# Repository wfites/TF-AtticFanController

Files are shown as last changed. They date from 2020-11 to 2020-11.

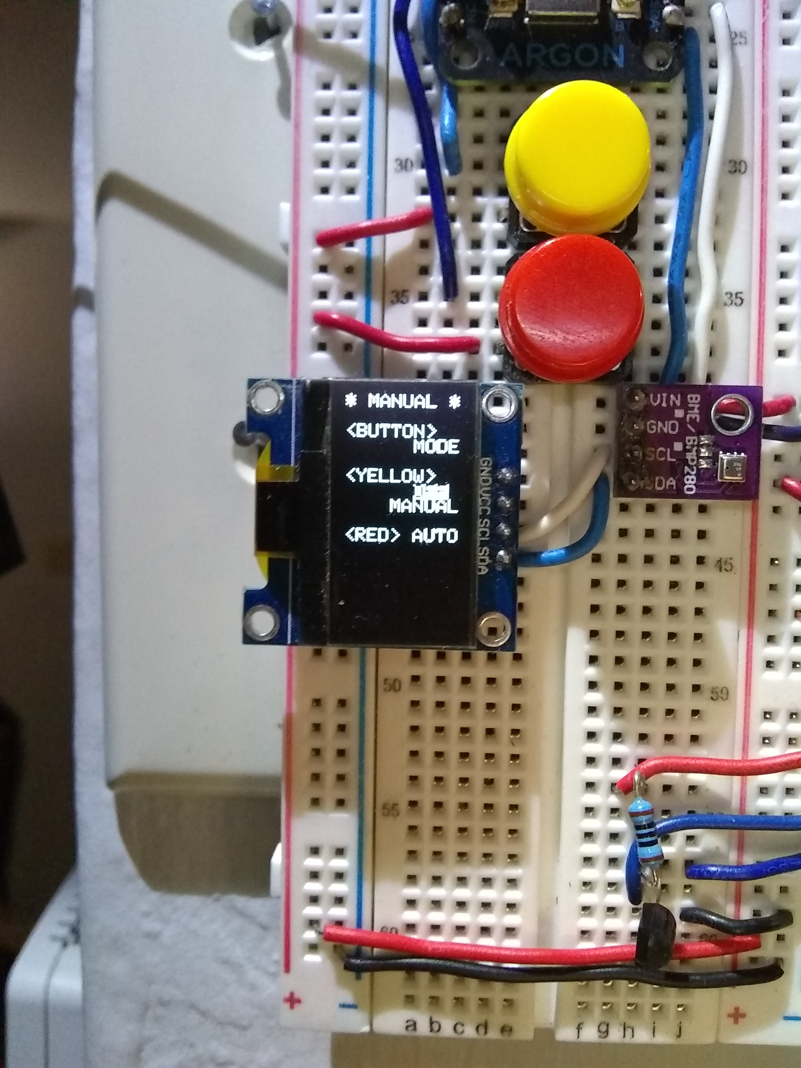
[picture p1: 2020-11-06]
Photos/ControllerManualModeScreen.jpg

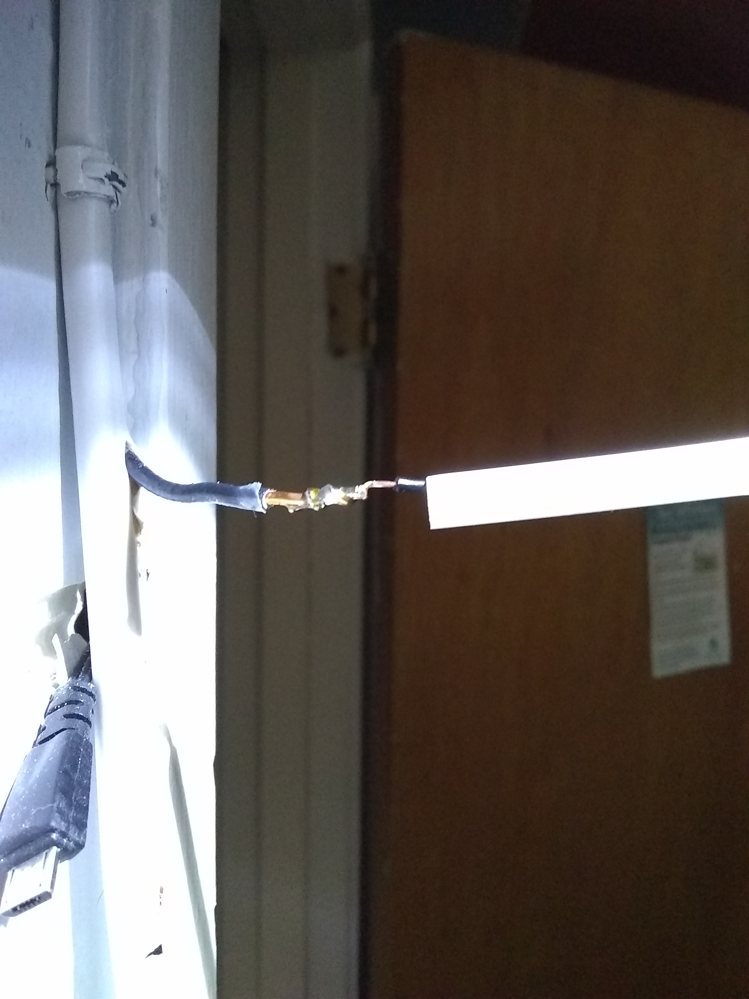
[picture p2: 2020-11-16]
Photos/Soldered14-18GaJointwHeatShrink.jpg

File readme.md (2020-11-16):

Attic Fan Controller: Project Progress
--------------------------------------
11/9/20:	Attic Fan Power Cord Channel Install
	Finish installing channel pcs 2 & 3 adj to door moulding, solder 14 ga extension wire pc#2/2 to spliced power cord hot wire, clean up debris around furnace closet. Install complete.

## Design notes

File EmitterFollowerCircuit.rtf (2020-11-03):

The common collector transistor circuit configuration gains its name from the fact that the collector circuit is common to both input and output circuits, the base being associated with only the input, then the emitter with the output only.

The other name for the common collector is emitter follower. This name is derived from the fact that the emitter voltage "follows" that of the base circuit - the circuit has unit voltage gain.

The emitter follower transistor amplifier has a very straightforward circuit. The base is connected to the previous stage, and often this may be directly connected as this can save on additional bias resistors which lower the input impedance and hence increase the loading to the previous stage.
Common collector transistor configuration showing the base connection common to both input and output circuits
Transistor common collector circuit configuration

Looking at the circuit it can be seen that although the emitter voltage follows that of the base, in DC terms it is actually less than that of the base by a voltage equal to the PN junction drop between the base and emitter. Typically this is 0.6 volts for a silicon transistor and 0.2 to 0.3 for germanium transistors, although these are not widely used these days.

As the emitter voltage follows that of the base, this means that the input and output are exactly in phase and not shifted by 180° as in the case of the common emitter amplifier.
Emitter follower transistor amplifier characteristics summary

The table below gives a summary of the major characteristics of the common collector, emitter follower transistor amplifier.

Common collector, emitter follower transistor amplifier characteristics

Parameter Characteristics
Current gain High
Voltage gain Zero
Power gain Medium
Input / output phase relationship 0°
Input resistance High
Output resistance Low

One key aspect of the characteristic is the input impedance. As it is normally used as a buffer amplifier, this is the key parameter.

The input resistance can easily be calculated for a circuit because it is â times the resistor R1, where â is the forward current gain of the transistor.
Emitter follower input impedance
Emitter follower input resistance
DC coupled emitter follower, common collector circuit

The simplest way of connecting an emitter follower is to directly couple the input as shown below. Often the collector of the previous stage will be at approximately the mid rail voltage, and this means that it can be directly coupled to the buffer stage.
Using a directly coupled emitter follower circuit
Directly coupled emitter follower circuit

Choose transistor: As with other forms of transistor circuit, the transistor should be chosen to meet the anticipated requirements.
Emitter resistor value: The voltage on the emitter is easy to define. It is simply that appearing at the previous stage. Say for example this is half the rail voltage, then the voltage on the emitter Q1 will be 0.5V (for a silicon transistor) less than this - the drop of the base emitter junction. Simply calculate the value of the resistor for the current required.
Emitter follower input resistance: The input resistance of the circuit is effectively â times the emitter resistor, R1.

AC coupled emitter follower, common collector circuit

It is not always possible to directly couple the emitter follower, common collector buffer. When this is the case, it is necessary to add a few additional electronic components: coupling capacitors and bias resistors to the circuit.
Emitter follower circuit with input and output AC coupling and bias resistors
AC coupled emitter follower circuit

The emitter follower can be designed and electronic component values determined using the design flow below as a basis:

Choose transistor: As before, the transistor type should be chosen according to the anticipated performance requirements.
Select emitter resistor: Choosing an emitter voltage of about half the supply voltage to give the most even range before the onset of any clipping, determine the current required from the impedance of the following stage.
Determine base current: The maximum base current is the collector current divided by â (or hfe which is essentially the same).
Determine the base voltage: The base voltage is simply the emitter voltage plus the base emitter junction voltage - this is 0.6 volts for silicon and 0.2 volts for germanium transistors.
Determine base resistor values: Assume a current flowing through the chain R1 + R2 of around ten times that of the base current required. Then select the correct ratio of the resistors to provide the voltage required at the base.
Determine value of input capacitor value: The value of the input capacitor should equal the resistance of the input circuit at the lowest frequency to give a -3dB fall at this frequency. The total impedance of the circuit will be â times R3 plus any resistance external to the circuit, i.e. the source impedance. The external resistance is often ignored as this is likely to not to affect the circuit unduly.
Determine output capacitor value : Again, the output capacitor is generally chosen to equal the circuit resistance at the lowest frequency of operation. The circuit resistance is the emitter follower output resistance plus the resistance of the load, i.e. the circuit following.
Re-evaluate assumptions: In the light of the way the circuit has developed, re-assess any circuit assumptions to ensure they still hold valid. Aspects such as the transistor choice, current consumption values, etc.

The emitter follower circuit is particularly useful for applications where a input high impedance is required. Offering a high input impedance and low output impedance it is does not load circuits that may only have a small output capability, or those circuits like oscillators that need a high impedance load to ensure the optimum stability, etc.
Emitter follower practical aspects

When using the emitter follower circuit, there are a useful few practical points to note:

Input capacitance affects RF: Although the emitter follower offers a high resistance to any signals, the base emitter capacitance may reduce the impedance if signals above a few hundred kilohertz are used. This should be remembered during the electronic circuit design as this can affect any loading levels significantly.

Collector may need decoupling: On some occasions an emitter follower circuit can oscillate, especially if long leads are present. This can happen when high frequency responses are needed and high frequency transistors are used.

One of the easiest ways of preventing this is to decouple the collector to ground using a capacitor, C3 with connections that are as short as reasonably possible. This can be easily incorporated during the electronic circuit design, and can be included as a precautionary measure using just a couple of electronic components.

Values will depend upon the frequency in use. If necessary a small value of resistance, R4, can be placed between the collector and the supply rail. The value of this resistor only needs to be of the order of 100Ù or less in most instances. This can also be added as a precaution.
Emitter follower circuit with collector decoupling
Emitter follower circuit with collector decoupling

The same effect can also be implemented by placing a small ferrite bead over the collector lead. However for most purposes the resistor / capacitor solution is the most convenient.

The emitter follower is simple to implement and requires only a few electronic components. It is a very convenient circuit to add when a circuit requires a minimum load to be placed upon it.

The common collector transistor circuit configuration gains its name from the fact that the collector circuit is common to both input and output circuits, the base being associated with only the input, then the emitter with the output only.

The other name for the common collector is emitter follower. This name is derived from the fact that the emitter voltage "follows" that of the base circuit - the circuit has unit voltage gain
**********************************************************************************
Emitter Current (I) where ohm's law = V =IR I= V/R
V=5v R=100 ohms I=.05 A or 50 mA
R=47 ohms I= .1063 A or 106 mA
measured at base-emitter junction: 180 mA
Base Current I=V/R
V=2.9V
R=2200 ohms
I= 2.9/2200 = .00131 A =1.31 mA
Current Gain: Emitter/Base 180/1.31 = 138X
6) PNP Transistor 2N3906
This bipolar junction transistor consists of a single N-type semi-conductor material (having surplus negative-charged carrier electons) sandwiched in between two P-type semiconductor material (having surplus positive-charged particles), with leads (legs) attached to each section. The middle lead is the base, with outer leads known as collector and emitter. This transistor has two PN junctions: base-collector, and base-emitter. Transistors often function as switches for integrated circuits, but our project circuit uses it as a current amplifier to supply current to the relay switch.
HOW THE PROJECT CIRCUIT WORKS
Activating the attic fan is largely dependent on the current generated within the input circuit through the transistor and on to the relay switch. The circuit's base-emitter junction is critical for generating the current. In this project circuit, a manual button press or automated activation sends output current to digital pin (D7). This current is then pushed by a smaller amount of voltage (where the circuit metered just under 3V ) along its circuit to the transistor's base lead, at which point this very small current then combines with higher current pushed from by the Argon's VUSB pin(metered at 5V) along the transistor's base-emitter junction, to the emitter lead, and finally to the IN connector at the relay switch.
The project's circuit operates in ACTIVE mode, where the transistor acts to amplify the current at the base-emitter junction through to the relay switch. Active mode can occur when voltage at the base-emitter junction reaches .7V (metered as .749V), and with only a very small base current relative to the emitter current (metered at 180 mV at the base-emitter junction). The relationship between emitter versus base current is known as DC current gain. Typical ratios can vary between 50-200, where the project circuit is calculated at 138 mA.
The circuit constructed for this project is called an emitter follower. This refers to the fact that the emitter voltage "follows" that of the base circuit; that is, the emitter circuit has unit voltage gain.

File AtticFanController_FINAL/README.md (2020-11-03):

# AtticFanController_FINAL

A Particle project named AtticFanController_FINAL

## Welcome to your project!

Every new Particle project is composed of 3 important elements that you'll see have been created in your project directory for AtticFanController_FINAL.

#### ```/src``` folder:  
This is the source folder that contains the firmware files for your project. It should *not* be renamed. 
Anything that is in this folder when you compile your project will be sent to our compile service and compiled into a firmware binary for the Particle device that you have targeted.

If your application contains multiple files, they should all be included in the `src` folder. If your firmware depends on Particle libraries, those dependencies are specified in the `project.properties` file referenced below.

#### ```.ino``` file:
This file is the firmware that will run as the primary application on your Particle device. It contains a `setup()` and `loop()` function, and can be written in Wiring or C/C++. For more information about using the Particle firmware API to create firmware for your Particle device, refer to the [Firmware Reference](https://docs.particle.io/reference/firmware/) section of the Particle documentation.

#### ```project.properties``` file:  
This is the file that specifies the name and version number of the libraries that your project depends on. Dependencies are added automatically to your `project.properties` file when you add a library to a project using the `particle library add` command in the CLI or add a library in the Desktop IDE.

## Adding additional files to your project

#### Projects with multiple sources
If you would like add additional files to your application, they should be added to the `/src` folder. All files in the `/src` folder will be sent to the Particle Cloud to produce a compiled binary.

#### Projects with external libraries
If your project includes a library that has not been registered in the Particle libraries system, you should create a new folder named `/lib/<libraryname>/src` under `/<project dir>` and add the `.h`, `.cpp` & `library.properties` files for your library there. Read the [Firmware Libraries guide](https://docs.particle.io/guide/tools-and-features/libraries/) for more details on how to develop libraries. Note that all contents of the `/lib` folder and subfolders will also be sent to the Cloud for compilation.

## Compiling your project

When you're ready to compile your project, make sure you have the correct Particle device target selected and run `particle compile <platform>` in the CLI or click the Compile button in the Desktop IDE. The following files in your project folder will be sent to the compile service:

- Everything in the `/src` folder, including your `.ino` application file
- The `project.properties` file for your project
- Any libraries stored under `lib/<libraryname>/src`

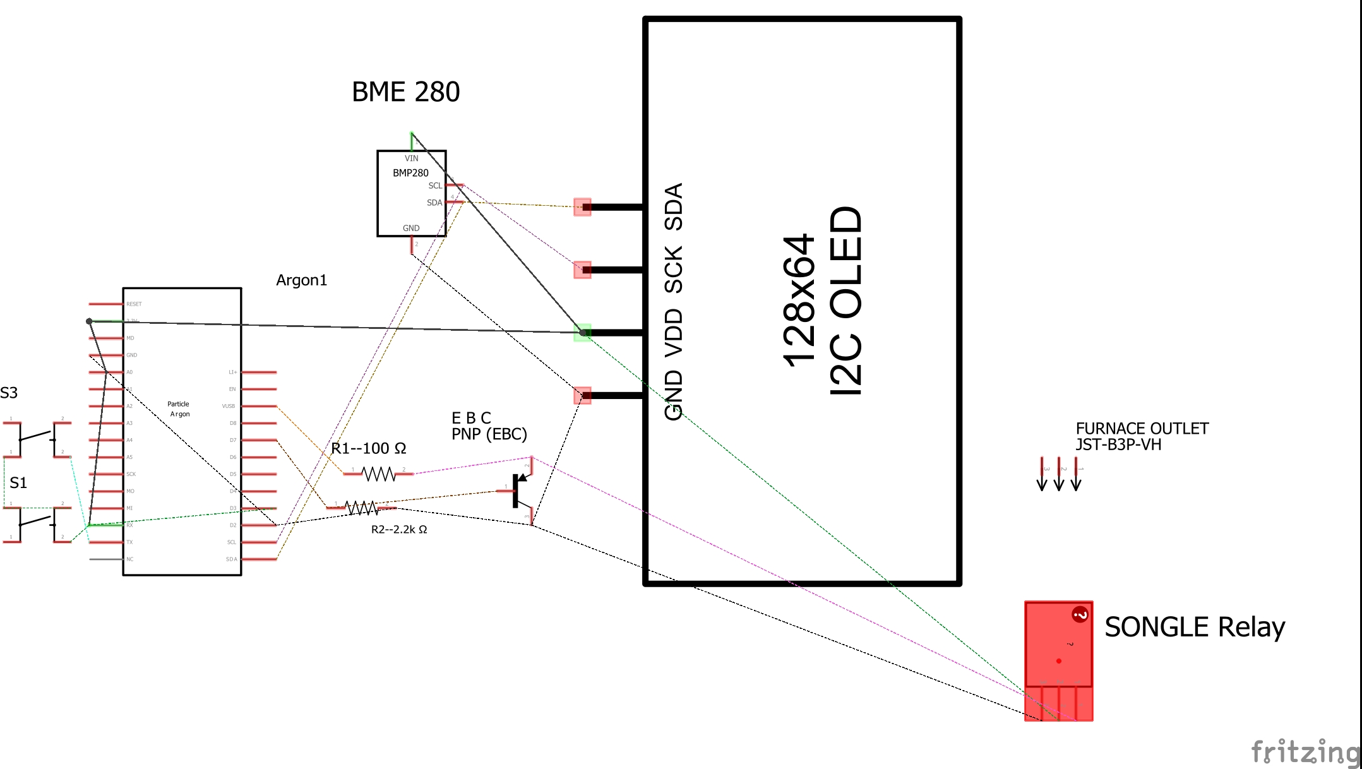
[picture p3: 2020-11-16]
AtticFanControllerSchematicExp.jpg

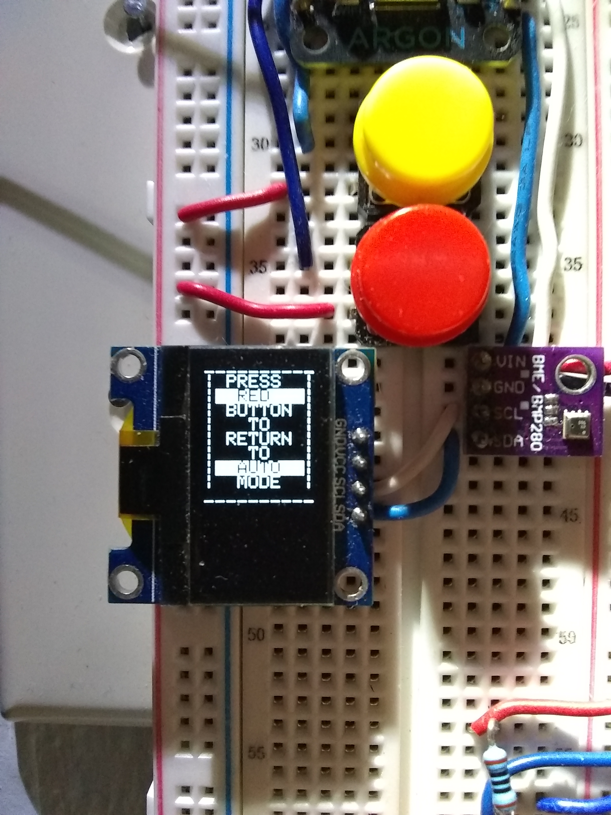
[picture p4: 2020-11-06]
Photos/ControllerWrongButtonPressScreen.jpg

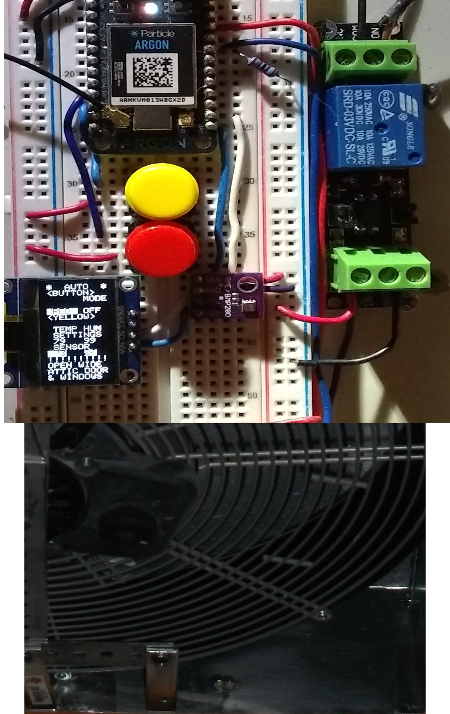
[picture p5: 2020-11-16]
Photos/HacksterIoMainphoto.jpg

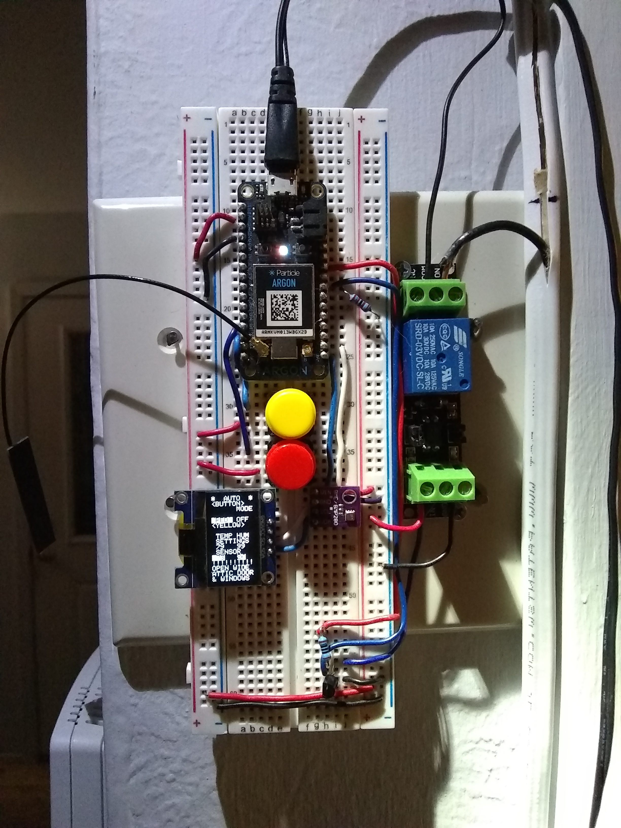
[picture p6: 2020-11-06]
Photos/BeadboardCircuitOnWall.jpg

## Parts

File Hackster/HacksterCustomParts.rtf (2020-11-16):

I) Floor fan
Item #758417Model #SFD1-500B Utilitech 20-in 3-Speed Indoor Black Painting Personal Fan $79.98
II) Attic Fan Compartment Hardware
Source: LOWES.com
Item #4508 Model #PBD-09-00001 5/8-in x 2-ft x 2-ft Commercial Particle Board $4.64
Item #36439 Model #GVL0107 IMPERIAL 16-in x 36-in Galvanized Steel Joist Lining $7.98 (2)
Item #308961 Model #20902ORXLG Gatehouse 3.5-in Bronze Die-cast Sliding Window Sash Lift $3.18
Item #35136 Model #B777CT40 Johns Manville Multi-Purpose R-5.33-sq ft Unfaced Fiberglass Roll Insulation (16-in W x 4-ft L) $5.90
Item #63403 Model #180147 Hillman 1/4-in Zinc-Plated Standard (SAE) Nylon Insert Lock Nut 0.13 (3)
Item #19165 Model #SP115BC Stanley-National Hardware 0.875-in x 4-in x 3.98-in Zinc-plated Flat Brace $3.27 (3)
Item #69811 Model #11139 Hillman 1-3/8-in x 3-ft Interior/Exterior Zinc-Plated Steel Perforated $5.98 (2)
Item #333358 Model #991210 1 x 8 x 8 PFJ Primed Board $16.98
Item #63306 Model #270055 Hillman 1/4-in Zinc-Plated Standard (SAE) Flat Washer 0.13 (9)
Item #61820 Model #190003 Hillman 1/4-in x 1/2-in Zinc-Plated Coarse Thread Hex Bolt
0.09 (9)
Item #154277 Model #1502104 1/2 x 2 x 4 AC/BC Fir Plywood $11.75
Item #648930 Model #N109-041 National Hardware 8/25-in Black Gate Hinge $4.78 (2)
Item #22249 Model #N222-232 National Hardware 1 Count 2.5-in W x 0.75-in L x 1/4-in Dia Zinc-plated U-Bolt
Item #220376 Model #605565 Gatehouse 2-1/2in Brass Fixed Staple Safety Hasp
Item no.5301072|01-3414-456 Ace 0.73 in. L Zinc Gate Hook and Eye 1 pk $2.39
III) Micro-controller Wall plate attachment & Attic Fan Power Cord Sheathing Hardware
Item #777903 Model #PJ23LA-F-LW Eaton 2-Gang Light Almond Double Blank Midsize Wall Plate $1.84
Item #1614082 Model #1709-F-LW Eaton 15-Amp 125-Volt Heavy-Duty NEMA 5-15 Straight Plug
Item #1614087 Model #2887-F-LW Eaton 15-Amp 125-Volt Heavy-Duty NEMA 5-15 Straight Connector $5.88
Item #302632 Model #28827426 Southwire Romex SIMpull 15-ft 14/2 Non-Metallic Wire (By-the-Roll) $8.33
IV) Attic Fan Power Cord Sheathing Hardware
Source: LOWES.com
Item #478822 Model #SP25NKUS Weller Electric Lead-Free Soldering Kit $19.97
Item #757555 Model #HST-187W Gardner Bender 5-Count 5mm 3-in Heat Shrink Tubing
Item #68996 Model #330485 NMW1 Legrand 5 Ft White PVC Channel $7.97 (3)
Item #69112 Model #363145 NMW6 Legrand WM White Flat Elbow $4.47
Item #69613 Model #363148 NMW910 Legrand WMOLD Accessory Pack $3.47 (2)

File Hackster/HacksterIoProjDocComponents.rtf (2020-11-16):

Hackster Account : Attic Fan Controller Compoents
II) Attic Fan Compartment Hardware
Source: LOWES.com
Item #4508Model #PBD-09-00001 5/8-in x 2-ft x 2-ft Commercial Particle Board $4.64
Item #36439Model #GVL0107 IMPERIAL 16-in x 36-in Galvanized Steel Joist Lining $7.98 (2)
Item #308961Model #20902ORXLG Gatehouse 3.5-in Bronze Die-cast Sliding Window Sash Lift $3.18
Item #35136Model #B777CT40 Johns Manville Multi-Purpose R-5.33-sq ft Unfaced Fiberglass Roll Insulation (16-in W x 4-ft L) $5.90
Item #63403Model #180147 Hillman 1/4-in Zinc-Plated Standard (SAE) Nylon Insert Lock Nut 0.13 (3)
Item #19165Model #SP115BC Stanley-National Hardware 0.875-in x 4-in x 3.98-in Zinc-plated Flat Brace $3.27 (3)
Item #69811Model #11139 Hillman 1-3/8-in x 3-ft Interior/Exterior Zinc-Plated Steel Perforated $5.98 (2)
Item #333358Model #991210 1 x 8 x 8 PFJ Primed Board $16.98
Item #63306Model #270055 Hillman 1/4-in Zinc-Plated Standard (SAE) Flat Washer 0.13 (24)
Item #61820Model #190003 Hillman 1/4-in x 1/2-in Zinc-Plated Coarse Thread Hex Bolt
0.09 (24)
Item #154277Model #1502104 1/2 x 2 x 4 AC/BC Fir Plywood $11.75

III) Attic Fan Power Cord Sheathing Hardware
Source: LOWES.com
Item #478822 Model #SP25NKUS Weller Electric Lead-Free Soldering Kit $19.97
Item #68996 Model #330485 NMW1 Legrand 5 Ft White PVC Channel $7.97 (3)
Item #69112 Model #363145 NMW6 Legrand WM White Flat Elbow $4.47
Item #69613 Model #363148 NMW910 Legrand WMOLD Accessory Pack $3.47 (2)

Elevator Pitch (140 char max)
Argon microcontroller converts a 3-speed floor fan into a whole-house air circulation system. Buttons select manual/auto fan operation.
Hackster.Io Story
This project repurposes a hi-power 3-speed floor fan for its new role as a whole house attic fan. Fan power is provided by constructing an active mode PNP circuit connected to a relay switch, powered by an Argon Microcontroller. The fan circulates air throughout the house, concentrating into a custom-built ceiling compartment that houses the fan, which fans air out into the attic space, which then exits via open garage windows.
The Argon is programmed for manual and automatic fan control operation. Manual mode operates just like an on-off switch. Automatic mode continuously checks for interior temperature or humidity exceeding their programmed thresholds beforing powering on the fan. Separate OLED screens show programmed menu button options to navigate and select the desired mode.
Once completing a working breadboard circuit, I began related work to complete the finalportion of the circuit: splicing the extension cord and soldering the spliced ends into the extended 14 ga wires connected to the COM ans NO conections of the tested breadboard circuit. After connecting the breaboard to the A/C circuit, I confirmed the fully completed circuit worked for manual andauto modes on Nov 6. This required plugging in a phone cord adapter cable from ther furnace closet power strip outlet to the microcontroller, for supplying power to the Argon, as well as connecting the fan's newly constructed power cord into the power strip to supply power to the fan, thus completing the entire circuit. The final phase of the project, constructing and installing PVC sheathing for the exposed power cord was completed on Nov. 11.
PROJECT DEVELOPMENT & TIMELINE
Development actually began prior to the start of the bootcamp on July 6. The project's first step involved constructing a plywood compartment to house the fan inside the existing swamp cooler air duct chamber. Compartment construction started in late May, finishing in late September, where the fan was successfully installed into the finished compartment. Having finished the compartment, fan cooling testing began for confirming that the house could be comfortably cooled down in the evenings, overnight and through morning. Fan testing extended from Sep 24-27. Results were successful, often reducing the temperature 9-10 degrees overnight through approx 10-11A next morning, when windows were shut and regular A/C was turned on.
Next, circuit design and circuit programming began the last week of September, starting with lab book circuit diagram, finishing with first draft Fritzing circuit diagram, and followed by initial lab book OLED display layouts. Breadboard circuit wiring began at the end of September after completing the first draft Fritzing diagram. During the first week of October, more hands on construction and testing took place for building the 15 ft long extension cord providing power from the nearby furnace closet outlet to the fan compartment, located nearby on the hallway ceiling. During the second week, first-configuration breadboard circuit was completed, followed by first draft programming logic revisions. C++ program logic revisions, debugging, testing and documentation continued throughweeks three and four (see above, section "Modifications") to ensure the circuit and button programming worked according to specs. During week three, I created the Github repository (AT-AtticFanController) to push completed separate versions of the C++ driver program, AtticFanController.
Once completing a working breadboard circuit, I began related work to complete the final portion of the circuit: splicing the extension cord and soldering the spliced ends into the extended 14 ga wires connected to the COM ans NO conections of the tested breadboard circuit. After connecting the breaboard to the A/C circuit, I confirmed the fully completed circuit worked for manual andauto modes on Nov 6. This required plugging in a phone cord adapter cable from ther furnace closet power strip outlet to the microcontroller, for supplying power to the Argon, as well as connecting the fan's newly constructed power cord into the power strip to supply power to the fan, thus completing the entire circuit. The final phase of the project, constructing and installing PVC sheathing for the exposed power cord was completed on Nov. 11.
ESSENTIAL PROJECT CIRCUIT COMPONENTS
These are the components for the programmed circuit:
1) Particle Argon Microcontroller
This is the processing unit controlling all its connected devices listed below that construct the project circuit. The 32-bit main processor runs at 64 MHz, offering WI-FI, Bluetooth & cellular network connections. Has its own OS, is used world-wide, and allows easy prototype-to-production source code options. Also has an expansive pin configuration for communicating with other devices, including up to 20 digital pins, 6 analog-to-digital conversion pins, and up to 13 analog pins. It's powered on 3.3 volts, with optional 5 volt capacity (a feature critical to this project).
2) Yellow & Red buttons
When pressed, these buttons complete a digital input circuit with the Argon to communicate the user's selected operation mode, and when it's currently activated and deactivated.
3) SSD 1306 OLED display (Adafruit)
This interface device, complete with its own library of programmable subroutines, communicates all essential information to users. It features menu-driven screens for selecting the operating mode (manual or auto), current BME sensor readings for temperature and humidity (and their programmed thresholds automatically triggering fan operation), and error button press messages during operation. This display screen, approximately 3/4"x1", uses an I2C serial communication protocol (being slaved off of the BME sensor). In this project, the display is programmed in portrait mode with a maximum 16 lines, at 10 characters per line, totaling 160 displayable characters.
4) BME 280 sensor (Adafruit)
This tiny device (approx 1/2" square) also features a complete libary of programmable routines, has sensing capabilities for temperature (in C), humidity and air pressure. For this project, its I2C serial communication data and clock pins are slaved directly from the Argon's corresponding SDA (data) and SCL (clock) pins. It features rapid, reliable sensing capability.
5) Relay Switch (Songle)
This switch is used to safely control an electrical device, such as the attic fan requiring higher current or higher voltage, from a mocrocontroller. The switch contains an electro-magnetic control coil, coming in contact with a switch powered from a digital pin on the Argon, that closes the circuit from the Argon.
6) PNP Transistor 2N3906
This bipolar junction transistor consists of a single N-type semi-conductor material (having surplus negative-charged carrier electons) sandwiched in between two P-type semiconductor material (having surplus positive-charged particles), with leads (legs) attached to each section. The middle lead is the base, with outer leads known as collector and emitter. This transistor has two PN junctions: base-collector, and base-emitter. Transistors often function as switches for integrated circuits, but our project circuit uses it as a current amplifier to supply current to the relay switch.
HOW THE PROJECT CIRCUIT WORKS
Activating the attic fan is largely dependent on the current generated within the input circuit through the transistor and through the output circuit and on to the relay switch. The circuit's base-emitter junction is critical for generating the current. In this project circuit, a manual button press or automated activation sends output current from digital pin (D7). This current is pushed by a smaller amount of voltage (metered just under 3V) along its circuit to the transistor's base lead, at which point this very small current then combines with higher current pushed from by the Argon's VUSB pin(metered at 5V) along the transistor's base-emitter junction, to the emitter lead, and finally to the IN connector at the relay switch.
From there, the circuit joins up with the furnace closet extension cord that provides A/C power to the attic fan. The relay switch is wired into the extension cord's hot (black) wire from the opposite side of the relay switch, into the COM (Common ground) and NO (Normally Open) connectors. When the Argon circuit is switched on, current travels from the relay switch and through these connectors to the two spliced ends of the hot wire, traveling to the fan motor along this wire, then exiting through the cord's white wire back to the outlet, to fully complete the circuit and power the fan. Then a reversal takes place: Current flows through the white wire into the fan, then exits out through the black wire (via the relay switch connection) as it exits back to the outlet. This A/C cycle is repeated 60 times per second.
The project's circuit operates in ACTIVE mode, where the transistor acts to amplify the current at the base-emitter junction through to the relay switch. Active mode can occur when voltage at the base-emitter junction reaches .7V (metered as .749V), and with only a very small base current relative to the emitter current (metered at 180 mV at the base-emitter junction). The relationship between emitter versus base current is known as DC current gain. Typical ratios can vary between 50-200, where the project circuit is calculated at 138 mA.
BASIC BUTTTON OPERATION
The major programming focus is simple, consistent operation, where the two major modes, manual and auto, work identically. Manual mode simply means pressing the yellow button to instantly switch ON the fan; pressing the same button again switches OFF the fan. Auto mode means pressing the red button to instantly activate continuous threshold level checks for temperature and humidity. At anytime when the sensor detects either temperature OR humidity readings at/above threshold, the fan is switched ON. At anytime when readings fall below both thresholds, the fan is switched OFF. Pressing the red button again instantly deactivates threshold checks. Threshold checks are presently set within the driver program (an advanced revision would allow threshold adjustments by button press, like on a thermostat).
OLED DISPLAY SCREENS
There are three separate OLED display screens, and are programmed for activation based on user button presses. A pair of YELLOW button presses (for switching on and off the fan) displays the same "Manual" OLED screen. A pair of RED button presses displays the "Auto" OLED screen. Either mode screens allows simple navigation to the alternate mode. However, a second button press for the button opposite from the first button press displays the Error press OLED screen.
The layout for each operation mode screen is described below:
I) MANUAL mode OLED screen
This screen appears when the driver program starts. From top to bottom lines, it consists of three major components:
-Operation mode ID line,
-Mode navigation header lines,
-Mode navigation option selection lines (with manual mode selections appearing first).
Here is a detailed breakdown for each line of the three components:
1) Header screen ID line, appearing as:
" MANUAL "
2) Button color (left-justified) and operation mode header labels (right-justified):
" <BUTTON>
MODE "
This layout style employs placing headers, normally adjacent on a single line, to be staggered over two lines, compensating for the OLED display's space restrictions. The button color header is delimited by angle brackets, <>, visually distinguishing it from the op mode header label.
3) Button color name and operation mode switch names associated for MANUAL mode:
" <YELLOW>
OFF
MANUAL "
This layout inherits multiple features from the staggered header lines, including labels justified and lining up under their associated headers, angle brackets for the button color name, and both switch names right-justified on separate lines for clear association. Valid selections are "OFF" or "MANUAL", while highlighting the active selection "MANUAL" upon button press.
4) Button color name and operation mode switch names associated for AUTO mode:
" <RED> AUTO "
Layout features here also inherit those from the header line. These are also both valid selections, one of which to be activated by pressing the RED button.
II) AUTOMATIC mode OLED screen
This mode uses the entire 16 lines to display mode-related info. From top to bottom lines, it consists of five major components:
-Operation mode ID line,
-Mode navigation header lines,
-Mode navigation option selection lines (with auto mode selections appearing first)
-BME temperature & humidity sensor data: separate lines for the two threshold settings,
followed by the two sensor readings
-Prep-related reminder instructions for opening the attic access door & house windows for proper air circulation
1) Header screen ID line, appearing as:
" AUTO "
2) Button color (left-justified) and operation mode header labels (right-justified):
" <BUTTON>
MODE "
3) Button color name and the opposing operation mode switch associated for AUTO mode:
" <RED> OFF "
The active, highlighted selection upon button press is <RED>.
4) Button color name and operation mode switch names associated for MANUAL mode:
" <YELLOW> "
5) Two lines for header labels displaying programmed temperature & humidity settings, followed by a third line displaying their values:
" TEMP HUM "
" SETTINGS "
" 99 99 "
6) One line for a summary header label for displaying sensor readings of temperature & humidity settings, followed by a second line displaying actual readings:
" SENSOR "
" 99 99 "
7) Four lines for drawing attention to and displaying reminder instructions for necessary prep-related duties:
" !!!!!!!!!! "
" OPEN WIDE "
" ATTIC DOOR "
" & WINDOWS "
These esential prep steps can be overlooked in auto mode because the fan may not be immediately activated (and which serves as the definitive reminder).
III) ERROR Press OLED screen
This screen appears when the button colors from the two consecutive button presses do not match; in effect, the user does not correctly toggle OFF the intial operating mode after toggling it ON. One of two separate error screens appear, depending on the press sequence:
1) If the YELLOW button is first pressed 2) If the RED button is first pressed
initating MANUAL mode, followed by a initating AUTO mode, followed by a YELLOW
RED button press (AUTO mode), this screen button press (MANUAL mode), this screen
appears: appears:
" PRESS " " PRESS "
" YELLOW " " RED "
" BUTTON " " BUTTON "
" TO " " TO "
" RETURN " " RETURN "
" TO " " TO "
" MANUAL " " AUTO "
" MODE " " MODE "

In either case, following the instruction returns the user back to the previous op mode and switch position.

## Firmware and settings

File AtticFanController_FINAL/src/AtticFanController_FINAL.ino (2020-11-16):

/*
 * Project AtticFanController_FINAL
 * Description:
 *  This is a post-IoT Bootcamp project following the Cohort 2 graduation on Sep 11, 2020.
 *  This project repurposes a hi-power 3-speed floor fan for its new role as a whole house attic 
 * fan. Power for the fan is provided by constructing an active-mode PNP circuit connected to a 
 * relay switch, powered by an Argon Miccrocontroller. The fan circulates air throughout the house,
 * concentrating into a custom-built ceiling compartment that houses the fan, which fans air out 
 * into the attic space, and then exited via open garage windows.
 * 	The Argon is programmed with manual and automatic operating modes for fan control. Manual 
 * mode operates just like an on-off switch. Automatic mode continuously checks for interior 
 * temperature or humidity exceeding their programmed thresholds beforing powering on the fan. 
 * Separate OLED screens show programmed menu options to operate buttons for selecting the active 
 * operation mode.
 *  	The controller, active-mode PNP circuit and relay switch components can be adapted for 
 * controlling a variety of household A/C appliances, such as ceiling fans and electric heaters, 
 * whenever the relay switch circuit can be spliced into the device's hot wire of the power cord. 

 *
 * Author: Ted Fites
 * 
 * Modifications:
 * 10/29/20   TF Completed FINAL version. Includes final modifications for OLED screens button 
 *              operation screen messages and up-to-date source code file documentation.
 * 10/26/20   TF Completed v#3. Includes tested functionality for wrong button press during operation.
 * 10/25/20   TF Completed v#2. Includes tested functionality for controller AUTO mode complimentary
 *              to MANUAL mode. Also transferred circuit from Argon breadboard to small breakout board
 *              (2"x6") for added wiring space & to eliminate short circuits on Argon board.
 * 10/14/20   TF Created program. Includes tested intial functionality for controller MANUAL mode.
 *
 */
//************************************* HEADER section ***************************************
//********************* 1) Declare program header library files ******************************
#include "Adafruit_SSD1306.h"  // library to access class object for OLED display 
#include "Adafruit_BME280.h"  // library to access class object BME sensor
#define OLED_RESET D4

// ******************* 2) Declare global CONSTANTS & VARIABLES  ******************************
const bool ON=1, OFF=0;  // button switch variables clarifying main loop conditional checks logic
const float AUTO_MIN_TEMP=79.0, AUTO_MIN_HUM=99.0;  // initial AUTO mode threshold temperature/humidity values
const int ORIENT_PORTRAIT=3; // sets OLED button operation screen orientation to portrait
const int MAN_MODE_BTN_D10=D10;  // digital input pin# for YELLOW button (MANUAL mode) 
const int AUTO_MODE_BTN_D11=D11;  // digital input pin# for RED button (auto mode) 
const int FAN_ACTIVATION_D7=D7;  // digital output pin# supplying DC to activate (close) relay switch circuit
const unsigned long int POWER_OFF_DELAY=10000; // delay program 10 seconds following fan power-off
const unsigned long int BUTTON_PRESS_DELAY=1000; // delay main loop execution 1 second to recognize button press

bool btnManualSt, btnAutoSt;  // stores DigitalRead states from manual and auto button presses
bool autoFanStatus=OFF;  // intial setting used in AUTO mode checking if fan currently turned ON or OFF
bool manMode=OFF, autoMode=OFF; // initial settings checking which controller operation mode is currently in effect
bool status;  // activation status check for BME280 sensor
float temperature, humidity;  // variables storing data from BME analog sensor reads
// Next 2 variables display "catch-all" console error messages used during testing button operation (should never see)
String ErrMsgManOLED = "OLED DISPLAY SWITCH CASE ERROR--M A N U A L  MODE";
String ErrMsgAutoOLED = "OLED DISPLAY SWITCH CASE ERROR--A U T O MODE";
// Next 3 variables display on OLED screen during button operation
String OpsMsgAutoMode = "OPEN WIDE ATTIC DOOR& WINDOWS"; // fan prep reminder message for AUTO button press
String OpsMsgFrame = "!!!!!!!!!!";
String WrongButtonMsgFrame = "__________";
unsigned long int startMillis, currMillis, totDelay;  // for calculating program execution delays
enum SwPressErr {WRONG_YELLOW_PRESS,WRONG_RED_PRESS};  // User data type clarifying logic for invalid mode switch press
  SwPressErr en_SwPressErr;

// ******************* end CONSTANTS & VARIABLES  ******************************
// ******************* 3) Declare library class objects ************************
Adafruit_SSD1306 display(OLED_RESET); // object for OLED display methods 
Adafruit_BME280 bme;  // object for BME sensor's variables
//********************* end  HEADER section ************************************

SYSTEM_MODE(SEMI_AUTOMATIC); // Argon mode allows project flashing while disconnected from any wifi internet
void setup()  //***********************  S E T U P *****************************
{
  Serial.begin(9600);

// 1) Initialize the I2C address to 0x3C to activate the OLED display (128x64 pixels screen)
  display.begin(SSD1306_SWITCHCAPVCC, 0x3C);  
  display.display(); // show Adafruit splashscreen to OLED
  delay(1000);  // maintain display for 1 second
  Serial.printf("PROGRAM AtticFanController_FINAL\n");

 // 2) BME 280sensor : Execute .begin method to activate sensor  
  delay (1000);
  Serial.println(F("BME280 test"));   
  status = bme.begin(0x76);  
    if (!status) {
        Serial.println("Could not find a valid BME280 sensor, check wiring, address, sensor ID!");
        Serial.print("SensorID was: 0x"); Serial.println(bme.sensorID(),HEX);
        Serial.println("        ID of 0xFF probably means a bad address, a BMP 180 or BMP 085");
        Serial.println("   ID of 0x56-0x58 represents a BMP 280,");
        Serial.println("        ID of 0x60 represents a BME 280.");
        Serial.println("        ID of 0x61 represents a BME 680.");
        while (1);
    }
    else {
      Serial.println("BME280 Up and Running");
    }

// 3) Declare program PIN MODES 
pinMode(MAN_MODE_BTN_D10,INPUT_PULLDOWN); // YELLOW button pin: Manual fan control 
pinMode(AUTO_MODE_BTN_D11,INPUT_PULLDOWN);  // RED button pin: Automatic fan control 
pinMode(FAN_ACTIVATION_D7,OUTPUT);  // Digital pin to activate Relay switch to power attic fan

// 4) Display initial OLED screen in MANUAL operation display mode (manual switch set OFF)
ML01_MANUAL_OPS_SCREEN(OFF);  
}  // end SETUP

/*****************************************************************************************
 *************************************  M A I N  L O O P  ********************************
 *****************************************************************************************
 * B U T T O N  P R O C E S S I N G  L O G I C  O V E R V I E W ********************************
 * When pressing either button, YELLOW (for manual mode), or RED (for auto mode) use this same 
 * basic processing logic:
 * 1) Display the active OLED button operation screen for the operation mode the user selects. 
 * When the program starts, the MANUAL operation mode OLED screen displays.The active switch 
 * setting appears highlighted on the OLED display. For manual mode, switch settings are labeled 
 * "<MANUAL>" (for ON) and "<OFF>". For auto mode, switch settings are labeled "<RED>" (for ON) 
 * and "<OFF>". Also for auto mode, current temperature and humidity alues are highlighted on the 
 * display.
 * 2) Check for a YELLOW or RED button press (for manual or auto mode respectively). The initial
 * button press switches ON the selected operation mode.
 * 3) Check for a mistaken button SWITCH press. This occurs when the user has already switched ON
 * (activated) a selected operation mode (manual or auto). Instead of switching OFF the same 
 * selected mode by correctly repressing the same button, the user presses the opposite button. 
 * When this occurs, display an OLED message to press the correct button, then return the user 
 * back to the original screen and original switch setting (before the mistaken button press). 
 * 4) Upon correct button press, set the active mode's switch opposite to its current setting, in 
 * effect activating the switch (ON to OFF, OFF to ON).
 * 5) Redisplay the OLED button operation screen to display the highlighted new switch setting 
 * (changed in the previous step).
 * 6) Check for active mode as switched OFF. If it is switched OFF, then deactivate 
 * current flow sent through the digital output pin D7 (via digitalWrite set to LOW/NO voltage). 
 * In effect, this deactivates current flow to the relay switch, which opens the relay switch 
 * circuit to the spliced extension cord hot (black) wire, thereby shutting off power to the attic 
 * fan. This deactivation occurs and lasts only at the instant of the button press.
 * 7) Check for active mode as switched ON. If it is switched ON, then activate  
 * current flow sent through the digital output pin D7 (via digitalWrite set to HIGH 
 * voltage). In effect, after the button is pressed to turn the switch ON, this maintains activation 
 * of current flow to the relay switch, which keeps the relay switch circuit closed to the spliced 
 * extension cord hot (black) wire, thereby maintaining power to the attic fan.
 *  This logic sequence is repeated for each button press while the program runs.
 ***************************************************************************************************/ 
void loop() 
{
  btnManualSt=digitalRead(MAN_MODE_BTN_D10);  // Check: YELLOW button press
  btnAutoSt=digitalRead(AUTO_MODE_BTN_D11);  // Check: RED button press

  if (btnManualSt)  // **** M A N U A L  M O D E  SELECTED  **********************************
/************************* Y E L L O W  BUTTON PRESS PROCESSING   ****************************
 * This processing occurs upon the instantaneous YELLOW button press                         *
 * *******************************************************************************************/
  {
    if (autoMode == ON)  
    { // Check for RED button pressed out of turn (AUTO mode) when already in manual mode
      autoMode=OFF; // switch the wrong mode setting (AUTO) to OFF
      en_SwPressErr=WRONG_RED_PRESS;
      ML05_WRONG_BUTTON_DISPLAY_SCREEN(); // display OLED screen explaining error & correction instruction
      goto MainLoopBottom;  // exit to loop bottom, leaving on error screen, waiting for next button press
    }  
    else
    { // For a valid press, switch MANUAL mode opposite to its current setting, then redisplay 
      // the OLED screen showing the new switch setting.
      manMode = !manMode;
      ML01_MANUAL_OPS_SCREEN(manMode);  
    }

    if (manMode == OFF)
    { // Check for MANUAL mode switched OFF. If so, deactivate current flow to the relay switch
//      Serial.printf("manMode O F F > %i\n",manMode);
      digitalWrite(FAN_ACTIVATION_D7,LOW);
    }
  }  
/************************* e n d Y E L L O W  BUTTON PRESS PROCESSING   ********************/

/* Now perform a continuous loop check for MANUAL mode switched ON. If so, activate current flow 
* to the relay switch. Maintain this current flow to the relay while the switch stays ON. 
*/
  if (manMode == ON)
  { 
//    Serial.printf("manMode O N > %i\n",manMode);
    digitalWrite(FAN_ACTIVATION_D7,HIGH);
  }

  if (btnAutoSt)  // ***** A U T O  M O D E  SELECTED  ***************************************
/************************* R E D   BUTTON PRESS PROCESSING   *********************************
 * This processing occurs upon the instantaneous RED button press                            *
 * *******************************************************************************************/
  {
    if (manMode == ON)  
    {  // Check for YELLOW button pressed out of turn (MANUAL mode) when already in auto mode
      manMode=OFF;
      en_SwPressErr=WRONG_YELLOW_PRESS;
      ML05_WRONG_BUTTON_DISPLAY_SCREEN();
      goto MainLoopBottom;
    }      
    else
    {
      autoMode = !autoMode;
      ML02_AUTO_OPS_SCREEN(autoMode);
      Serial.printf("AUTOMode  > %i\n",autoMode);
    }
  /* Check if AUTO mode is switched off. Next, check if the fan is switched ON based  on either 
  * the temperature or humidity reaching their programmed thresholds. If so, then deactivate the 
  * fan, followed by a 10 second fan blade cessation period.
  */
    if (autoMode == OFF)
    {
      if (autoFanStatus == ON)
      {
        Serial.printf("MAIN LOOP:AUTOMode is O F F > %i\n",autoMode);
        autoFanStatus = OFF;
        digitalWrite(FAN_ACTIVATION_D7,LOW);
        ML04_TIME_DELAY(POWER_OFF_DELAY);     
      }
    }
  }  
/************************* e n d  R E D  BUTTON PRESS PROCESSING   ********************/

/* Now perform a continuous loop check for AUTO mode switched ON. While the switch is ON,
* perform a continuous, automatic check on the temperature and humidity thresholds to see
* if either threshold will trigger on the relay switch. Following the treshold checks, 
* redisplay the auto OLED screen to display continuously updated changes in temp or humidity.
*/
  if (autoMode == ON)
  {
    Serial.printf("AUTOMode is O N > %i execute ML03_CHECK_AUTO_THRESHOLDS()\n",autoMode);
    ML03_CHECK_AUTO_THRESHOLDS();
    ML02_AUTO_OPS_SCREEN(autoMode);
  }
MainLoopBottom:
  ML04_TIME_DELAY(BUTTON_PRESS_DELAY);     
}  
/****************************    end  M A I N  L O O P  ************************************
 *******************************************************************************************/ 

/********************   OLED DISPLAY: M A N U A L   O P  M O D E  **************************/
void ML01_MANUAL_OPS_SCREEN(bool inManMode)
{
  display.clearDisplay();
  display.setTextSize(1);
  display.setTextColor(WHITE);
  display.setCursor(0,0);
  display.setRotation(ORIENT_PORTRAIT);
  display.print("* MANUAL *");
  display.println();
  display.printf("<BUTTON>\n");
  display.printf("      MODE\n");
  display.printf("<YELLOW>\n");
  switch (inManMode)
  {
    case OFF:
      display.setTextColor(WHITE);
      display.printf("      ");
      display.setTextColor(BLACK,WHITE);
      display.printf("OFF\n");
      display.setTextColor(WHITE);
      display.printf("    MANUAL\n");
      display.printf("<RED> AUTO\n");
      break;
    case ON:
      display.setTextColor(WHITE);
      display.printf("      OFF\n");
      display.printf("    ");
      display.setTextColor(BLACK,WHITE);
      display.printf("MANUAL\n");
      display.setTextColor(WHITE);
      display.printf("<RED> AUTO\n");
      break;
    default:
      display.println(ErrMsgManOLED);
      break;
  }
  display.display();
  return;
}

/********************   OLED DISPLAY--UPPER SCREEN: A U T O  O P  M O D E  ************/
void ML02_AUTO_OPS_SCREEN(bool inAutoMode)
{
  display.clearDisplay();
  display.setTextSize(1);
  display.setTextColor(WHITE);
  display.setCursor(0,0);
  display.setRotation(ORIENT_PORTRAIT);
  display.print("*  AUTO  *");
  display.printf("<BUTTON>\n");
  display.printf("      MODE\n");
/* BUTTON OPERATION INSTRUCTIONS "STYLE" TO HIGHLIGHT ACTIVE AUTO MODE SETTING:
* Use .setTextColor "inverted" text settings to highlight either the target mode button ("RED"), 
* indicating the active operation mode (and implying it's also switched ON), OR the auto 
* mode's deactivate switch setting ("OFF"). This mode selection style differs from both highlighted 
* manual operation mode selection settings, demonstrating a hyper-concise operation selection 
* style adaptable to very small display screens.
*/
  switch (inAutoMode)
  {
    case OFF:
      display.printf("<RED>");
      display.setTextColor(BLACK,WHITE);
      display.printf(" OFF\n");
      display.setTextColor(WHITE);
      display.printf("<YELLOW>\n");     
      ML02_2_AUTO_OPS_SCREEN();
      break;
    case ON:
      display.setTextColor(BLACK,WHITE);
      display.printf("<RED>");
      display.setTextColor(WHITE);
      display.printf(" OFF\n");
      display.printf("<YELLOW>\n");     
      ML02_2_AUTO_OPS_SCREEN();
      break;
    default:
      display.println(ErrMsgAutoOLED);
      break;
  }      
  display.display();
  return;
}

/********************   OLED DISPLAY--LOWER SCREEN: A U T O  O P  M O D E  ************
* This function is called from its parent function (ML02_AUTO_OPS_SCREEN()) to finish displaying
* information to the auto mode display screen, and called from two locations, specific to which 
* is the active auto switch setting in effect. 
*/
void ML02_2_AUTO_OPS_SCREEN()
{
  display.setTextColor(WHITE);
  display.println();
  display.printf(" TEMP HUM\n");
  display.printf(" SETTINGS\n");
  display.printf(" %2.0f   %2.0f\n",AUTO_MIN_TEMP,AUTO_MIN_HUM);
  display.printf(" SENSOR\n");
  display.setTextColor(BLACK,WHITE);
  display.printf(" %2.0f",temperature);
  display.setTextColor(WHITE);
  display.printf("   ");
  display.setTextColor(BLACK,WHITE);
  display.printf("%2.0f\n",humidity);
  display.setTextColor(WHITE);
  display.print(OpsMsgFrame);
  display.println(OpsMsgAutoMode);
//  display.println(OpsMsgFrame);
  return;
}
void ML03_CHECK_AUTO_THRESHOLDS()
{
  temperature=bme.readTemperature() * (9.0/5.0) + 32.0;
  humidity=bme.readHumidity();
  Serial.printf("AUTOMode TEMPERATURE > %2.0f\n",temperature);
  Serial.printf("AUTOMode HUMIDITY > %2.0f\n",humidity);
  if ((temperature >= AUTO_MIN_TEMP) || (humidity >= AUTO_MIN_HUM))
  {
    autoFanStatus=ON;
    digitalWrite(FAN_ACTIVATION_D7,HIGH);
  }
  else
  {
    autoFanStatus=OFF;
    digitalWrite(FAN_ACTIVATION_D7,LOW);
  }
  return;
}

void ML04_TIME_DELAY(unsigned long int inDelay)
{
  startMillis=millis();
  currMillis=0;
  totDelay=startMillis + inDelay;
  while(currMillis < totDelay)
  {
    currMillis=millis();
  }
  return;
}

/********************   OLED DISPLAY:  W R O N G   B U T T O N   P R E S S   ************
* This display screen appears whenever the user doesn't use the selected button mode (manual or
* auto) as a proper toggle switch; that is, to press tha same button once to switch ON the operation
* mode, followed by a second press to switch OFF the mode. 
*/
void ML05_WRONG_BUTTON_DISPLAY_SCREEN()
{
  char strBtnYellow[10] = " YELLOW ";
  char strBtnRed[10] =    "  RED   ";
  char strOpModeMan[10] = " MANUAL ";
  char strOpModeAuto[10] ="  AUTO  ";

  display.clearDisplay();
  display.setTextSize(1);
  display.setTextColor(WHITE);
  display.setCursor(0,0);
  display.setRotation(ORIENT_PORTRAIT);
  display.print(WrongButtonMsgFrame);
  display.print("| PRESS  |");
  display.printf("|");
  display.setTextColor(BLACK,WHITE);
  switch (en_SwPressErr)
  {
    case WRONG_YELLOW_PRESS: 
      display.printf("%s",strBtnYellow);
      break;
    case WRONG_RED_PRESS:  
      display.printf("%s",strBtnRed);
      break;
  }
  display.setTextColor(WHITE);
  display.print("|");
  display.print("| BUTTON |");
  display.print("|   TO   |");
  display.print("| RETURN |");
  display.print("|   TO   |");
  display.print("|");
  display.setTextColor(BLACK,WHITE);
  switch (en_SwPressErr)
  {
    case WRONG_YELLOW_PRESS: 
      display.printf("%s",strOpModeMan);
      break;
    case WRONG_RED_PRESS:  
      display.printf("%s",strOpModeAuto);
      break;
  }
  display.setTextColor(WHITE);
  display.print("|");
  display.print("|  MODE  |");
  display.print(WrongButtonMsgFrame);
  display.display();
  return;
}

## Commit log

2020-10-21 AtticFanController completed modifications to ML01_MANUAL_OPS_SCREEN
    [AtticFanController.fzz]
2020-10-27 New AtticFanController_v3 includes wrong button pressed check
    [AtticFanController_v3.ino]
2020-10-28 Finished AtticFanController_v3 includes wrong button press processing
    [AtticFanController_v3.ino]
2020-11-06 Added Photos folder viewing mounted breadboard on wall after final circuit testing
2020-11-16 Includes 2 Hackster work files + 1 folder
    [AtticFanController.fzz]
